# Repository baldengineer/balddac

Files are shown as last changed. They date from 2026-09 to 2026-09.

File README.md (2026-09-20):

# Bald DAC Wing

Open hardware KiCad project for a two-channel, high-speed digital-to-analog converter (DAC) board.

The design is built around the Analog Devices AD5447 dual 12-bit multiplying current-output DAC and includes fast output amplification, a precision reference, digital interface logic, coaxial outputs, and test points. Revision 1 has been prepared for fabrication.

## Features

- Dual 12-bit current-output DAC channels
- AD8065 high-speed output amplifier stages
- REF3425 2.5 V voltage reference
- Parallel digital interface with registered/control logic
- Separate coaxial outputs for DAC A and DAC B
- 3.3 V digital power and dedicated analog/reference power nets
- Four-layer PCB stackup with internal copper planes
- Custom KiCad symbols for project-specific parts

## Status

Revision 1 was sent to fabrication.

## License

This project is released under the [MIT License](LICENSE).

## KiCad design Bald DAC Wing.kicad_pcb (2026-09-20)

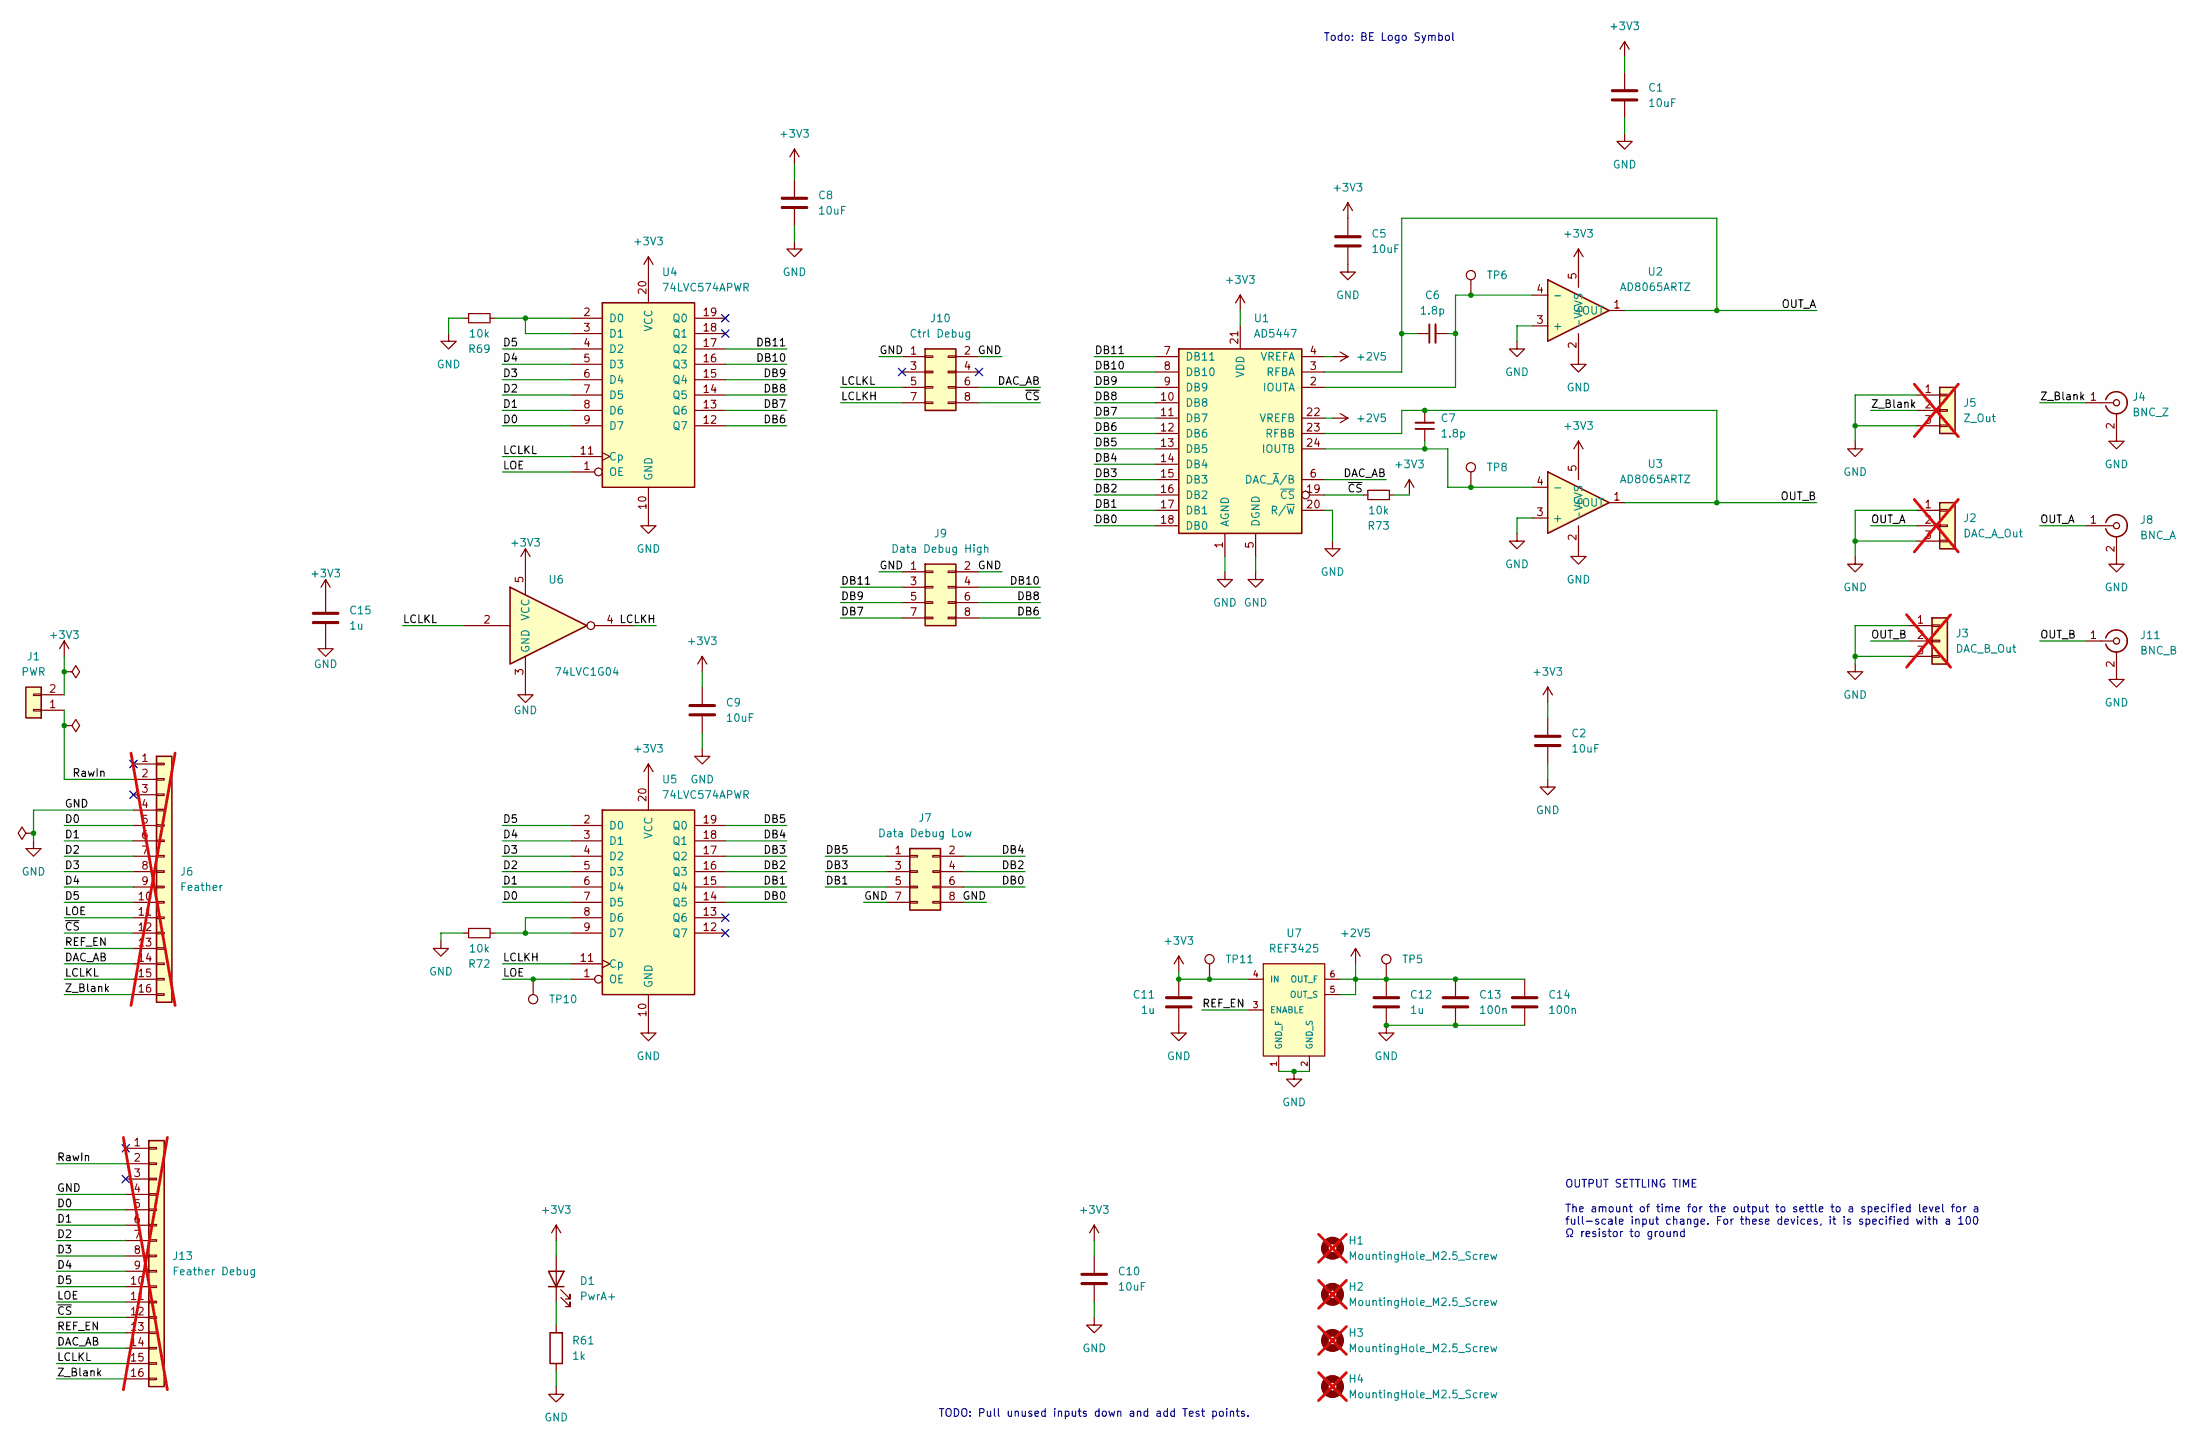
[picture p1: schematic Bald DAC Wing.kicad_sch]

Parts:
C1, C2, C5, C8, C9, C10: 10uF; C_0805_2012Metric_Pad1.18x1.45mm_HandSolder; LCSC C15850
C6, C7: 1.8p; C_0603_1608Metric_Pad1.08x0.95mm_HandSolder; LCSC C282244
C11, C12, C15: 1u; C_0805_2012Metric_Pad1.18x1.45mm_HandSolder; LCSC C15850
C13, C14: 100n; C_0402_1005Metric_Pad0.74x0.62mm_HandSolder; LCSC C307331
D1: PwrA+; LED_0805_2012Metric_Pad1.15x1.40mm_HandSolder; LCSC C2297
H1, H2, H3, H4: MountingHole_M2.5_Screw; MountingHole_2.7mm_M2.5; LCSC N/A; not fitted
J1: PWR; PinHeader_1x02_P2.54mm_Vertical
J2: DAC_A_Out; PinHeader_1x03_P2.54mm_Vertical; LCSC N/A; not fitted
J3: DAC_B_Out; PinHeader_1x03_P2.54mm_Vertical; LCSC N/A; not fitted
J4: BNC_Z; Molex_73100-0105_BNC_RA; Mouser 538-73100-0105
J5: Z_Out; PinHeader_1x03_P2.54mm_Vertical; LCSC N/A; not fitted
J6: Feather; PinSocket_1x16_P2.54mm_Vertical; not fitted
J7: Data Debug Low; PinHeader_2x04_P2.54mm_Vertical
J8: BNC_A; Molex_73100-0105_BNC_RA; Mouser 538-73100-0105
J9: Data Debug High; PinHeader_2x04_P2.54mm_Vertical
J10: Ctrl Debug; PinHeader_2x04_P2.54mm_Vertical
J11: BNC_B; Molex_73100-0105_BNC_RA; Mouser 538-73100-0105
J13: Feather Debug; PinSocket_1x16_P2.54mm_Vertical; not fitted
R61: 1k; R_0603_1608Metric_Pad0.98x0.95mm_HandSolder; LCSC C21190
R69, R72, R73: 10k; R_0603_1608Metric_Pad0.98x0.95mm_HandSolder; LCSC C25804
TP5, TP6, TP8, TP10, TP11: TestPoint_Harwin; Harwin-S1751-46-Test-Point; LCSC C3029083
U1: AD5447; TSSOP-24_4.4x7.8mm_P0.65mm; LCSC C514217
U2, U3: AD8065ARTZ; SOT-23-5; LCSC C9648
U4, U5: 74LVC574APWR; TSSOP-20_4.4x6.5mm_P0.65mm; LCSC C7672
U6: 74LVC1G04; SOT-23-5; LCSC C7827
U7: REF3425; SOT-23-6; LCSC C187836

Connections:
+2V5: C12.1, C13.1, C14.1, TP5.1 (1_1), U1.4 (VREFA), U1.22 (VREFB), U7.5 (OUT_S), U7.6 (OUT_F)
+3V3: C1.1, C2.1, C5.1, C8.1, C9.1, C10.1, C11.1, C15.1, D1.2 (A), J1.2, R73.2, TP11.1 (1_1), U1.21 (VDD), U2.5 (+VS), U3.5 (+VS), U4.20 (VCC), U5.20 (VCC), U6.5 (VCC), U7.4 (IN)
/D0: J6.5, J13.5, U4.9 (D7), U5.7 (D5)
/D1: J6.6, J13.6, U4.8 (D6), U5.6 (D4)
/D2: J6.7, J13.7, U4.7 (D5), U5.5 (D3)
/D3: J6.8, J13.8, U4.6 (D4), U5.4 (D2)
/D4: J6.9, J13.9, U4.5 (D3), U5.3 (D1)
/D5: J6.10, J13.10, U4.4 (D2), U5.2 (D0)
/DAC_AB: J6.14, J10.6, J13.14, U1.6 (DAC_~A/B)
/DB0: J7.6, U1.18 (DB0), U5.14 (Q5)
/DB1: J7.5, U1.17 (DB1), U5.15 (Q4)
/DB2: J7.4, U1.16 (DB2), U5.16 (Q3)
/DB3: J7.3, U1.15 (DB3), U5.17 (Q2)
/DB4: J7.2, U1.14 (DB4), U5.18 (Q1)
/DB5: J7.1, U1.13 (DB5), U5.19 (Q0)
/DB6: J9.8, U1.12 (DB6), U4.12 (Q7)
/DB7: J9.7, U1.11 (DB7), U4.13 (Q6)
/DB8: J9.6, U1.10 (DB8), U4.14 (Q5)
/DB9: J9.5, U1.9 (DB9), U4.15 (Q4)
/DB10: J9.4, U1.8 (DB10), U4.16 (Q3)
/DB11: J9.3, U1.7 (DB11), U4.17 (Q2)
/LCLKH: J10.7, U5.11 (Cp), U6.4
/LCLKL: J6.15, J10.5, J13.15, U4.11 (Cp), U6.2
/LOE: J6.11, J13.11, TP10.1 (1_1), U4.1 (OE), U5.1 (OE)
/OUT_A: C6.1, J2.2, J8.1 (In), U1.3 (RFBA), U2.1 (OUT)
/OUT_B: C7.2, J3.2, J11.1 (In), U1.23 (RFBB), U3.1 (OUT)
/REF_EN: J6.13, J13.13, U7.3 (ENABLE)
/RawIn: J1.1, J6.2, J13.2
/Z_Blank: J4.1 (In), J5.2, J6.16, J13.16
/~CS: J6.12, J10.8, J13.12, R73.1, U1.19 (~CS)
GND: C1.2, C2.2, C5.2, C8.2, C9.2, C10.2, C11.2, C12.2, C13.2, C14.2, C15.2, J2.1, J2.3, J3.1, J3.3, J4.2 (Ext), J5.1, J5.3, J6.4, J7.7, J7.8, J8.2 (Ext), J9.1, J9.2, J10.1, J10.2, J11.2 (Ext), J13.4, R61.1, R69.1, R72.1, U1.1 (AGND), U1.5 (DGND), U1.20 (R/~W), U2.2 (-VS), U2.3 (+), U3.2 (-VS), U3.3 (+), U4.10 (GND), U5.10 (GND), U6.3 (GND), U7.1 (GND_F), U7.2 (GND_S)
unnamed: D1.1 (K), R61.2
unnamed: C6.2, TP6.1 (1_1), U1.2 (IOUTA), U2.4 (-)
unnamed: C7.1, TP8.1 (1_1), U1.24 (IOUTB), U3.4 (-)
unnamed: R69.2, U4.2 (D0), U4.3 (D1)
unnamed: R72.2, U5.8 (D6), U5.9 (D7)

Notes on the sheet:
OUTPUT SETTLING TIME The amount of time for the output to settle to a specified level for a full-scale input change. For these devices, it is specified with a 100 Ω resistor to ground
Todo: BE Logo Symbol
TODO: Pull unused inputs down and add Test points.

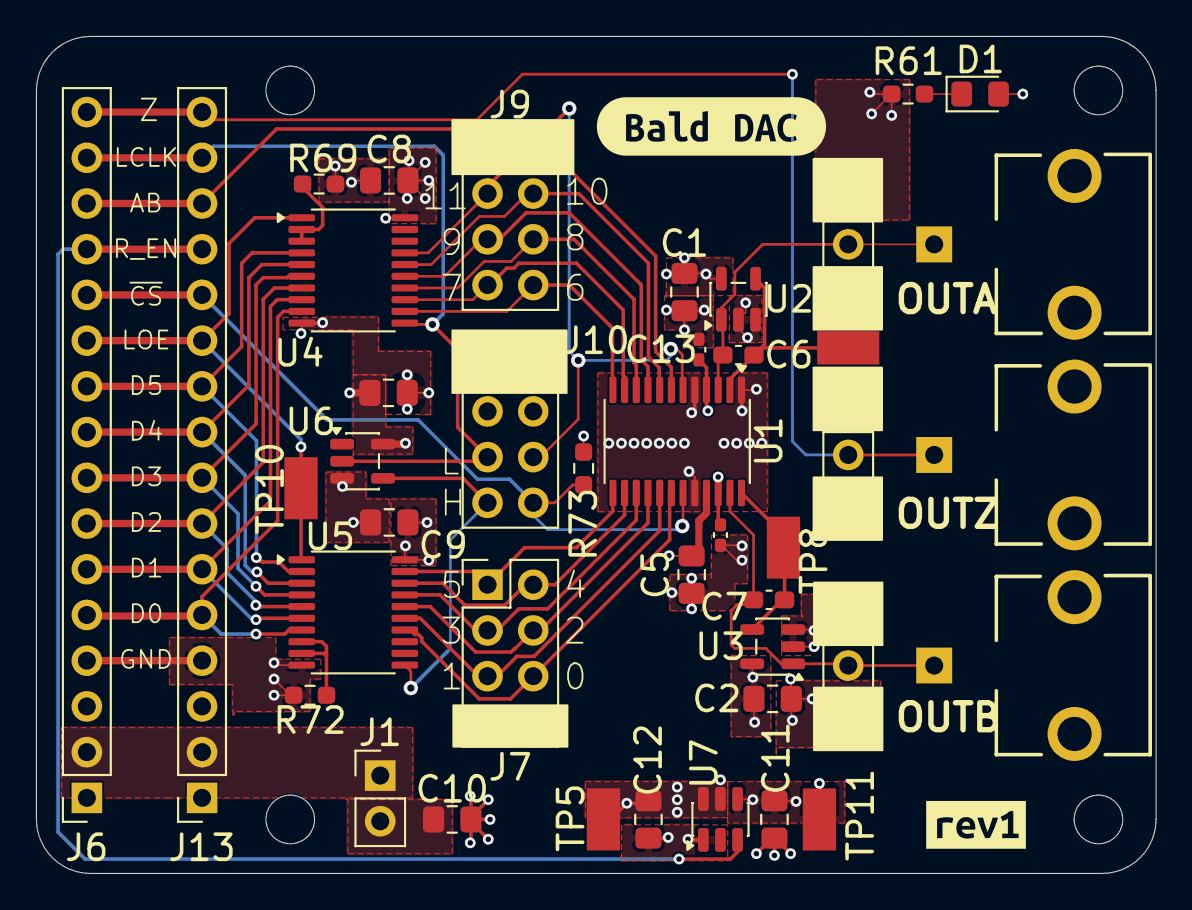
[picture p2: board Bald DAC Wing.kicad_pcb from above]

Board: 4 copper layers, 62.2 x 46.5 mm, 48 parts (0 on the bottom side), 36 nets.

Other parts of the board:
kibuzzard-6AB056B3: G***; kibuzzard-6AB056B3
kibuzzard-6AB05686: G***; kibuzzard-6AB05686

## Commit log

2026-08-27 wondering about 20k 0.01%
    [Bald DAC Wing.kicad_pcb, Bald DAC Wing.kicad_sch]
2026-08-27 First pass schematic. going to give to clanker to see if it can populate the pcb logically.
    [Bald DAC Wing.kicad_sch]
2026-08-27 bailing on discrete version. makes no sense.
    [Bald DAC Wing.kicad_sch]
2026-08-28 starting over with ICs
    [Bald DAC Wing.kicad_sch]
2026-08-31 latches in place. need to decide on VEE and what to use for Vref (ADR03?)
    [Bald DAC Wing.kicad_sch]
2026-08-31 Codex fixes. Check the chat history for examples of good suggestions.
    [Bald DAC Wing.kicad_sch]
2026-09-03 added REF3425, low-drop out 2.5v ref
    [Bald DAC Wing.kicad_sch]
2026-09-08 added a reference circuit. still need to change the cap values
    [Bald DAC Wing.kicad_pcb, Bald DAC Wing.kicad_sch]
2026-09-19 clanker is finaly working
    [Bald DAC Wing.kicad_pcb, Bald DAC Wing.kicad_sch]
2026-09-19 updated part numbs and changed to 1 gate inverter
    [Bald DAC Wing.kicad_sch]
2026-09-19 updated some caps
    [Bald DAC Wing.kicad_sch]
2026-09-19 thinking wings
    [Bald DAC Wing.kicad_sch]
2026-09-19 added adafruit wing and started wiring
    [Bald DAC Wing.kicad_sch]
2026-09-19 minor changes before astra review
    [Bald DAC Wing.kicad_sch]
2026-09-19 grouped pcb boards based on schematic location
    [Bald DAC Wing.kicad_pcb]
2026-09-19 remvoed courtyard from Feather footprint so I can put stuff inside of it.
    [Bald DAC Wing.kicad_pcb]
2026-09-19 only use 1/2 the feather!
    [Bald DAC Wing.kicad_pcb, Bald DAC Wing.kicad_sch]
2026-09-19 applied 4-layer DRC for OSH Park
    [Bald DAC Wing.kicad_pcb]
2026-09-19 got rid of the switches
    [Bald DAC Wing.kicad_sch]
2026-09-19 added power header
    [Bald DAC Wing.kicad_pcb, Bald DAC Wing.kicad_sch]
2026-09-19 first edge cut layer
    [Bald DAC Wing.kicad_pcb, Bald DAC Wing.kicad_sch]
2026-09-20 1st rough layout
    [Bald DAC Wing.kicad_pcb, Bald DAC Wing.kicad_sch]
2026-09-20 ditched feather footprint and went discete. also realized board could be covering
    [Bald DAC Wing.kicad_pcb, Bald DAC Wing.kicad_sch]
2026-09-20 broke-up debug headers and squeeshed the board some moar.
    [Bald DAC Wing.kicad_pcb, Bald DAC Wing.kicad_sch]
2026-09-20 It's getting there
    [Bald DAC Wing.kicad_pcb, Bald DAC Wing.kicad_sch]
2026-09-20 added BNCs for ABZ
    [Bald DAC Wing.kicad_pcb, Bald DAC Wing.kicad_sch]
2026-09-20 added JLC constraints (imported from clanker template)
    [Bald DAC Wing.kicad_pcb, Bald DAC Wing.kicad_sch]
2026-09-20 data buses are done. see optimizations, but going to finish
    [Bald DAC Wing.kicad_pcb, Bald DAC Wing.kicad_sch]
2026-09-20 removed Test Points for output because BNC and header pins give plenty of probe points
    [Bald DAC Wing.kicad_pcb, Bald DAC Wing.kicad_sch]
2026-09-20 doing power planes
    [Bald DAC Wing.kicad_pcb]
2026-09-20 time to clean-up silks.
    [Bald DAC Wing.kicad_pcb]
2026-09-20 Using Consola font and hide the warning that TextT Thickness is bad.
    [Bald DAC Wing.kicad_pcb]
2026-09-20 DRC pass with a silk warning that I'm okay with. Minor overlap.
    [Bald DAC Wing.kicad_pcb]
2026-09-20 gonna try and submit.
    [Bald DAC Wing.kicad_pcb]
2026-09-20 lcsc PNs updated for actuals in order. rev1 sent to fab.
    [Bald DAC Wing.kicad_pcb, Bald DAC Wing.kicad_sch]
